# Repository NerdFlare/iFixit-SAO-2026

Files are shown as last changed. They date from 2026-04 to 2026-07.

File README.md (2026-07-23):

# 2026 iFixit SAO

This repository contains the firmware and supporting files for 2026 iFixit Shitty Add On (SAO) featuring multiple LED animation modes, an interactive soldering challenge, and user-programmable firmware.

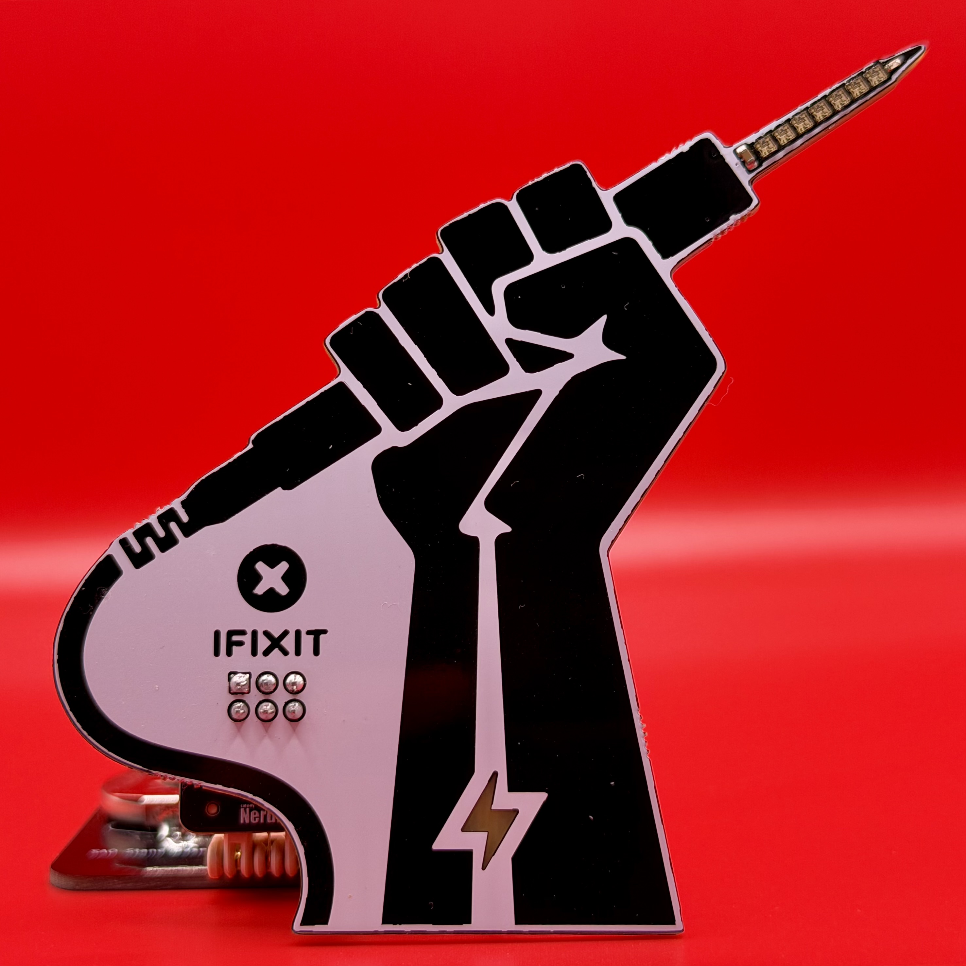
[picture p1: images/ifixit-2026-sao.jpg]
2026 iFixit SAO


## Project Structure

The repository is organized into three main directories:

```text
.
├── art/
├── code/
└── pcb/
```

### `art`

The [`art`](art/) directory contains the visual artwork used to create the badge. Each layer of the badge artwork is provided in SVG format, making it possible to inspect, modify, or reuse the individual design elements.

### `code`

The [`code`](code/) directory contains the badge firmware. It is configured as a PlatformIO project and uses the Arduino framework for the ATtiny1604-SS microcontroller.

See the [Programming the Badge](#programming-the-badge) section for more information about building and uploading the firmware.

### `pcb`

The [`pcb`](pcb/) directory contains the KiCad project files for the badge, including the electrical schematic and PCB layout.

## How the Badge Operates

The badge has three default animation modes:

1. **Off**
2. **Candle**
3. **Propane**

Press the button to cycle through the available modes. Each press advances the badge to the next mode.

The **lightning-bolt animation is always active**, regardless of which animation mode is selected.

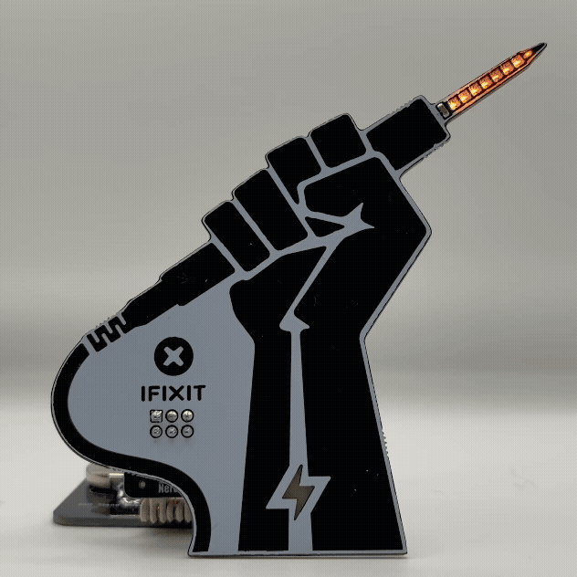
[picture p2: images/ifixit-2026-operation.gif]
Default animation modes


## Soldering Challenge

An additional animation mode can be unlocked by completing the badge's surface-mount soldering challenge.

Solder the following **0 Ω resistors** onto the indicated footprints:

| Footprint | Resistor size | Resistor value |
|---|---:|---:|
| `R5` | 1206 | 0 Ω |
| `R7` | 0805 | 0 Ω |
| `R9` | 0603 | 0 Ω |
| `R11` | 0402 | 0 Ω |

Once all four resistors are installed correctly, the badge will unlock an additional animation mode.

For convenience, resistors of the correct sizes and values are already installed in the following locations:

| Challenge footprint | Donor footprint |
|---|---|
| `R5` | `R6` |
| `R7` | `R8` |
| `R9` | `R10` |
| `R11` | `R12` |

You can desolder the resistors from `R6`, `R8`, `R10`, and `R12`, then resolder them onto their corresponding challenge footprints. You may also use your own 0 Ω resistors instead.

> [!TIP]
> Start with the largest component, the 1206 resistor, and work toward the smallest. Use plenty of flux, fine-point tweezers, an adequate magnification—especially for the 0402 resistor, and of course, an [iFixit FixHub](https://www.ifixit.com/Store/FixHub)!

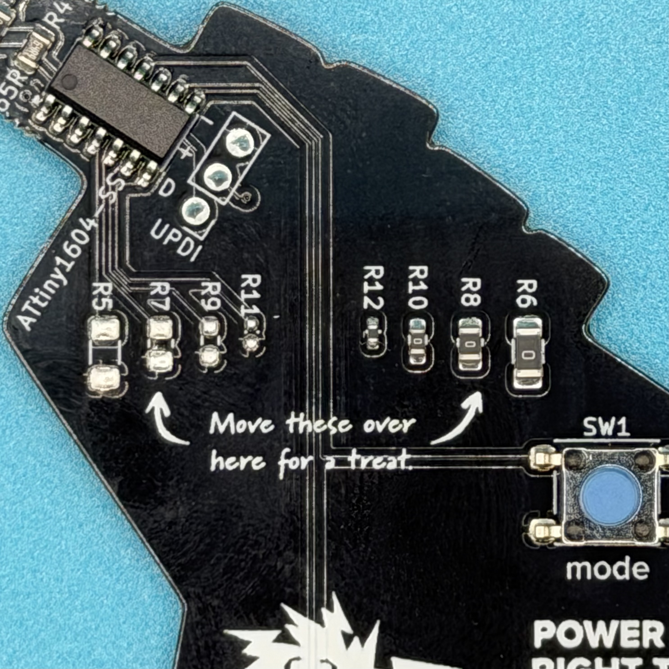
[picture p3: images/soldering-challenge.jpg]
Soldering challenge


## Programming the Badge

The badge is controlled by an **ATtiny1604-SS** microcontroller.

It can be programmed using the **UPDI** protocol through the exposed programming pads on the PCB. The programming pads use a **2.54 mm pitch**, making them compatible with common pin headers, pogo-pin adapters, or jumper-wire connections. The pads are labled D (for data), + (for postiive voltage), and - (for ground). 

A programmer such as the **Adafruit UPDI Friend** can be used to upload firmware to the badge.

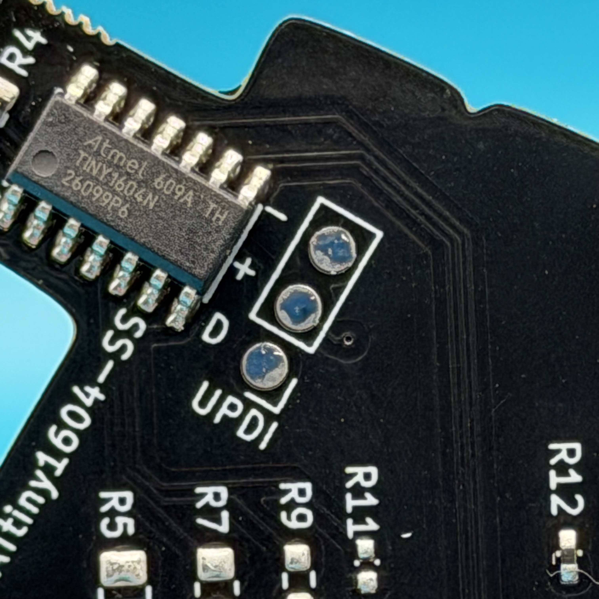
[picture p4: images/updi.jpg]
UPDI programming pads


### Firmware

The badge firmware is located in the [`code`](code/) directory.

The firmware is configured as a **PlatformIO** project and uses the **Arduino framework**. Open the `code` directory as a PlatformIO project to build or modify the firmware.

A typical workflow is:

1. Install [Visual Studio Code](https://code.visualstudio.com/).
2. Install the [PlatformIO IDE extension](https://platformio.org/install/ide?install=vscode).
3. Open the [`code`](code/) directory in PlatformIO.
4. Connect a UPDI programmer to the badge's programming pads.
5. Build and upload the firmware.

> [!CAUTION]
> The badge is designed to operate on 3.3V. Confirm the programmer voltage and all programming-pad connections before powering or programming the badge. Incorrect wiring may damage the microcontroller or programmer.

## Collaboration

This PCB art badge was created as a collaboration between [**iFixit**](https://ifixit.com), the [**Cal Poly NerdFlare club**](https://www.instagram.com/nerdflareslo/), and [**znjp**](https://www.instagram.com/_znjp_/).

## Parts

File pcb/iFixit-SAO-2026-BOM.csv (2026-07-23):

Id | Designator | Footprint | Quantity | Designation | Supplier and ref | Datasheet
1 | C1, C2 | C_0603_1608Metric | 2 | 0.1uF
2 | D1, D2 | SunLED 3.2x2.8mm PLCC2 SMD LED | 2 | LED | SunLED XZM2CYK45WT-9 | https://www.sunledusa.com/products/spec/XZM2CYK45WT-9.pdf
3 | D3 | LED_0402_1005Metric | 1 | LED | SunLED XZMDK68W-2
5 | LED1, LED2, LED3, LED4, LED5, LED6, LED7 | SK6508-EC 15 | 7 | SK6805-EC 15 | Shenzhen Normand Electronic | https://www.normandled.com/upload/202003/SK6805-EC15 LED Datasheet.pdf
7 | R1, R2, R4 | R_0805_2012Metric | 3 | 65R
8 | R3 | R_0805_2012Metric | 1 | 500R
9 | R5, R7, R9, R11 | DO NOT POPULATE |  | R
10 | R6 | R_1206_3216Metric_Pad1.30x1.75mm_HandSolder | 1 | 0R
12 | R8 | R_0805_2012Metric_Pad1.20x1.40mm_HandSolder | 1 | 0R
14 | R10 | R_0603_1608Metric_Pad0.98x0.95mm_HandSolder | 1 | 0R
16 | R12 | R_0402_1005Metric_Pad0.72x0.64mm_HandSolder | 1 | 0R
17 | SAO1 | SHITTY_ADD-ON_V1.69BIS SAO | 1 | ~ | Würth Elektronik 61200621621
18 | SW1, SW2 | SW_SPST_PTS645Sx43SMTR92 | 2 | SW_Push | C&K PTS645SM43SMTR92 LFS
19 | TP1 | TestPoint_Keystone_5019_Miniature | 1 | SAO Tether | Keystone Electronics 5019 | https://www.keyelco.com/userAssets/file/K75p61.pdf
20 | U1 | SOIC-14_3.9x8.7mm_P1.27mm | 1 | ATtiny1604-SS | Microchip Technology ATTINY1604-SSNR | https://ww1.microchip.com/downloads/en/DeviceDoc/ATtiny804-06-07-1604-06-07-DataSheet-DS40002312A.pdf

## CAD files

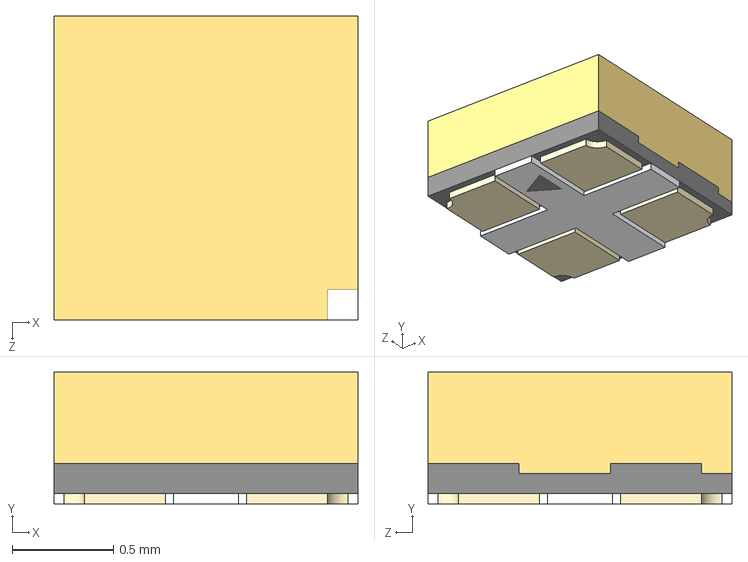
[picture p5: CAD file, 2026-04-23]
pcb/SK6508-EC 15.step
1.50 x 0.65 x 1.50 mm

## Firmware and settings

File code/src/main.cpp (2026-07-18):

/*
             *************             
         *********************         
       *************************       
     *****************************     
   *********************************   
  *********   ***********   *********  
 *********       *****       ********* 
 **********                 ********** 
************               ************
**************           **************
**************           **************
************               ************
 **********                 ********** 
 *********       *****       ********* 
  *********   **********    *********  
   *********************************   
     *****************************     
       *************************       
         *********************         
             *************
            iFixit SAO 2026
              Version 0.1
*/

#include <Arduino.h>
#include <EEPROM.h>
#include <tinyNeoPixel.h>

//Lightning Bolt
const int D1 = PIN_PB0; //Top
const int D2 = PIN_PB1; //Bottom
//Soldering iron tip
const int D3 = PIN_PA4;
//Button
const int BTN = PIN_PA1;
//Soldering Game
const int R5 = PIN_PA6;
const int R7 = PIN_PA7;
const int R9 = PIN_PB3;
const int R11 = PIN_PB2;
//Neopixels
const int NEOPIXEL = PIN_PA5;
const int PIXEL_COUNT = 7;
tinyNeoPixel strip = tinyNeoPixel(PIXEL_COUNT, NEOPIXEL, NEO_GRB);

//Animation modes
int num_modes_addr = 255;
int NUM_MODES = EEPROM.read(num_modes_addr);
int mode_addr = 254;
int MODE = EEPROM.read(mode_addr);

//Button pressed
bool pressed = true;

//fire aniamtion variables
unsigned long lastNeopixelUpdate = 0;
const int frameDelay = 40; // ms between animation frames
uint8_t heat[PIXEL_COUNT];

//rainbow animation
int rainbox_index = 0;

//D3 LED Tip
unsigned long lastD3Update = 0;
int brightness = 0;  // how bright the LED is
int fadeAmount = 1;  // how fast do we fade

//D1, D2 Lightning animation variables
enum State {
  WAITING,
  TOP_ON,
  BOTTOM_ON,
  TOP_DIM,
  FLASH,
  IMPACT,
  FADE_OUT,
  FLICKER
};
State state = WAITING;
unsigned long stateStart = 0;
unsigned long waitTime = 1000;
int fadeValue = 255;

// Input a value 0 to 255 to get a color value.
// The colours are a transition r - g - b - back to r.
uint32_t Wheel(byte WheelPos) {
  WheelPos = 255 - WheelPos;
  if (WheelPos < 85) {
    return strip.Color(255 - WheelPos * 3, 0, WheelPos * 3);
  }
  if (WheelPos < 170) {
    WheelPos -= 85;
    return strip.Color(0, WheelPos * 3, 255 - WheelPos * 3);
  }
  WheelPos -= 170;
  return strip.Color(WheelPos * 3, 255 - WheelPos * 3, 0);
}

// Converts a heat value (0-255) to a blue flame color
uint32_t propane(uint8_t temperature) {

  // Scale temperature
  uint8_t t = (temperature * 255) / 255;

  // Very cool = off/dim blue
  if (t < 60) {
    return strip.Color(0, 0, t * 2);
  }

  // Medium = deep blue
  else if (t < 140) {
    uint8_t b = 150 + (t - 60);
    uint8_t g = (t - 60) / 3;
    return strip.Color(0, g, min(255, b));
  }

  // Hot = cyan/blue-white core
  else if (t < 220) {
    uint8_t g = 80 + (t - 140);
    uint8_t b = 255;
    uint8_t r = (t - 140) / 8;
    return strip.Color(r, min(255, g), b);
  }

  // Hottest = small white core
  else {
    uint8_t w = t - 220;
    return strip.Color(40 + w, 180 + w, 255);
  }
}

// Converts a heat value (0-255) to a yellow flame color
uint32_t candle(uint8_t temperature) {

  uint8_t t192 = (temperature * 191) / 255;

  uint8_t heatramp = (t192 & 0x3F) << 2;

  // Cool -> red
  if (t192 > 0x80) {
    // Hot -> red/yellow
    return strip.Color(255, 50 + (heatramp/3), 0);
  }
  else if (t192 > 0x40) {
    // Medium -> orange/yellow
    return strip.Color(255, heatramp + 40, 0);
  }
  else {
    // Low -> dark red
    return strip.Color(heatramp, 0, 0);
  }
}

void updateFire(bool which) {

  // Step 1: Cool down every cell a little
  for (int i = 0; i < PIXEL_COUNT; i++) {
    int cooldown = random(0, 25);
    heat[i] = max(0, heat[i] - cooldown);
  }

  // Step 2: Heat drifts upward
  for (int i = PIXEL_COUNT - 1; i >= 2; i--) {
    heat[i] = (heat[i - 1] + heat[i - 2] + heat[i - 2]) / 3;
  }

  // Step 3: Random sparks near the "hot" end
  if (random(255) < 160) {
    int y = random(2); // ignite near the base
    heat[y] = min(255, heat[y] + random(160, 255));
  }

  // Step 4: Convert heat to LED colors
  for (int i = 0; i < PIXEL_COUNT; i++) {
    if(which){
      strip.setPixelColor(i, propane(heat[i]));
    }else{
      strip.setPixelColor(i, candle(heat[i]));
    }
  }

  strip.show();
}


void setup() {

  pinMode(PIN_PB0, OUTPUT);
  pinMode(PIN_PB1, OUTPUT);
  pinMode(D3, OUTPUT);
  pinMode(NEOPIXEL, OUTPUT);
  pinMode(BTN, INPUT_PULLUP);
  pinMode(R5, INPUT_PULLUP);
  pinMode(R7, INPUT_PULLUP);
  pinMode(R9, INPUT_PULLUP);
  pinMode(R11, INPUT_PULLUP);
        
  strip.setBrightness(25);
  for (int i = 0; i < strip.numPixels(); i++) {
    strip.setPixelColor(i, 0,0,0);
  }
  strip.show(); // Initialize all neopixels to 'off'

  if (NUM_MODES > 4){ NUM_MODES = 3;}
  if (MODE > NUM_MODES){ MODE = 0;}

  analogWrite(D1, 0);
  analogWrite(D2, 0);
  analogWrite(D3, 0);

}

void loop() {
  
  unsigned long now = millis();

  //Soldering Game (enable bonus mode)
  if(NUM_MODES == 3 && digitalRead(R5) == LOW && digitalRead(R7) == LOW && digitalRead(R9) == LOW && digitalRead(R11) == LOW){
    NUM_MODES = 4;
    MODE = 3;
    EEPROM.update(num_modes_addr,NUM_MODES);
  }

  //Handle Button
  if (digitalRead(BTN) == LOW && !pressed){
    pressed = true;
    MODE = (MODE + 1) % NUM_MODES;
    EEPROM.update(mode_addr,MODE);
    delay(20);     // Short delay to debounce button.
  }
  if (digitalRead(BTN) == HIGH){
    pressed = false;
    delay(20);
  }

  //Fade Red LED
  if(now - lastD3Update >= 10 && MODE != 2){
    lastD3Update = now;
    analogWrite(D3, brightness);
    brightness = brightness + fadeAmount;
    if (brightness <= 0 || brightness >= 128) {
      fadeAmount = -fadeAmount;
    }
  }else{
    analogWrite(D3, 0);
  }

  //Animate Neopixels
  switch (MODE){
    case 0:
    //Candle Animation
      if (now - lastNeopixelUpdate >= frameDelay) {
        lastNeopixelUpdate = now;
        updateFire(false);
      }
      break;
    case 1:
    //Propane Animation
      if (now - lastNeopixelUpdate >= frameDelay) {
        lastNeopixelUpdate = now;
        updateFire(true);
      }
      break;
    case 2:
    //Iron Off
      for (int i = 0; i < strip.numPixels(); i++) {
        strip.setPixelColor(i, 0);
      }
      strip.show();
      break;
    case 3:
    //Rainbox Animation (BONUS)
      if (now - lastNeopixelUpdate >= 10){
        lastNeopixelUpdate = now;
        for (int i = strip.numPixels() - 1; i >= 0; i--) {
          strip.setPixelColor(i, Wheel(((i * 64) + rainbox_index) & 255));
          rainbox_index = (rainbox_index+1)%256;
        }
        strip.show();
      }
      break;
  }

  //Animate Lightening Bolt
  switch (state) {
    case WAITING:
      if (now - stateStart >= waitTime) {
        analogWrite(D1, 255);
        analogWrite(D2, 0);
        state = TOP_ON;
        stateStart = now;
      }
      break;
    case TOP_ON:
      // Slower initial buildup
      if (now - stateStart >= 120) {
        analogWrite(D2, 255);
        state = BOTTOM_ON;
        stateStart = now;
      }
      break;
    case BOTTOM_ON:
      if (now - stateStart >= 150) {
        analogWrite(D1, 80);
        state = TOP_DIM;
        stateStart = now;
      }
      break;
    case TOP_DIM:
      if (now - stateStart >= 120) {
        analogWrite(D1, 255);
        analogWrite(D2, 255);
        state = FLASH;
        stateStart = now;
      }
      break;
    case FLASH:
      if (now - stateStart >= 80) {
        analogWrite(D1, 0);
        analogWrite(D2, 255);
        state = IMPACT;
        stateStart = now;
      }
      break;
    case IMPACT:
      // Hold the bottom glow longer
      if (now - stateStart >= 350) {
        fadeValue = 255;
        state = FADE_OUT;
        stateStart = now;
      }
      break;
    case FADE_OUT:
      // Gradual fade every 20ms
      if (now - stateStart >= 20) {
        fadeValue -= 15;
        if (fadeValue < 0) {
          fadeValue = 0;
        }
        analogWrite(D2, fadeValue);
        stateStart = now;
        if (fadeValue == 0) {
          // Optional secondary flicker
          if (random(100) < 40) {
            analogWrite(D1, 120);
            analogWrite(D2, 200);
            state = FLICKER;
            stateStart = now;
          } else {
            state = WAITING;
            stateStart = now;
            waitTime = random(2000, 5000);
          }
        }
      }
      break;
    case FLICKER:
      if (now - stateStart >= 120) {
        analogWrite(D1, 0);
        analogWrite(D2, 0);
        state = WAITING;
        stateStart = now;
        waitTime = random(2000, 5000);
      }
      break;
  }
}

// <3 znjp 

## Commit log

2026-04-15 Added an edge cut to design.
2026-04-23 Initial add of the symbol and footprint libraries, including the SK6508-EC, and an initial pcb layout.
    [SK6508-EC 15.step, iFixit-SAO-2026.kicad_pcb, iFixit-SAO-2026.kicad_sch]
2026-05-07 Update from our April 29th meeting.
    [iFixit-SAO-2026.kicad_pcb, iFixit-SAO-2026.kicad_sch]
2026-05-08 A complete prototype of v0 of the badge, ready for production and assembly. Cleaned up the schematic quite a bit, added teh UDPI programming pads, and updated the SK6508 footprint silkscreen.
    [iFixit-SAO-2026.kicad_pcb, iFixit-SAO-2026.kicad_sch]
2026-05-10 Version v0 sent for PCBA prototype.
    [iFixit-SAO-2026.kicad_pcb]
2026-05-29 Version 0.1 (fixed split ground planes, removed button, added new graphics); initial commit of firmware; adding individual pcb layer svgs
    [iFixit-SAO-2026.kicad_pcb, iFixit-SAO-2026.kicad_sch]
2026-07-18 Version 0.1 - FINAL: art, code, and PCB. 1000 made for DEFCON34
    [iFixit-SAO-2026.kicad_pcb, iFixit-SAO-2026.kicad_sch]
2026-07-23 Added BOM and README.
    [iFixit-SAO-2026-BOM.csv]
